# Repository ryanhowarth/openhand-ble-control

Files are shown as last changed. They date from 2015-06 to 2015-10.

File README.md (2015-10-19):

## Openhand Pancake

Wireless control of openhand using either RFduino microcontroller over BLE or Photon microcontroller over WiFi. Solidworks files of the actual pancake are also included. 

### Setup/ Usage
Setup and usage of both microcontrollers is described in README files located in *photon-software* and *rfduino-software*.

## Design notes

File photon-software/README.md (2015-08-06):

## openhand-wifi-control

Wireless control of openhand using an Particle Photon Microcontroller with WiFi to send and receive commands from the Dynamixel.

### Setup
This setup was tested with Xubuntu 14.04 and TL-WR841N Wireless Router.

Connect the Photon to a Wifi Network using the Particle CLI or using the Particle Mobile App.

Connect your computer to the same network and note your computer's local IP Address. Replace the *server_IP* address at the top of the *photon_hand_control.ino* script with the your own local address. Flash this scipt to the photon. 

### Usage
Start the TCP Socket Server by running the following python script. Next, turn on the Photon. The Photon should connect to the TCP Server shortly after booting. If the Photon starts blinking red, it has failed to connect to the server and will try again shortly.

```shell
python openhand_control.py
```

If this script is stopped, the Photon must be power cycled in order to reconnect to a new TCP Server.

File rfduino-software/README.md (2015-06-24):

## openhand-ble-control

Wireless control of openhand using an RFduino with ble to send and receive commands from the Dynamixel.

### Setup

This setup was tested with Xubuntu 14.04 and Bluez 5.21

Upload *rfduino_hand_control.ino* to your RFduino.

Install pygatt to magange the BLE connection: https://github.com/ampledata/pygatt
Using pip:
```shell
pip install pygatt
```
In order to work properly, the pygatt source need to be edited so gatttool works with random device types. 

Bluez version > 5.5 is needed for pygatt. This must be installed from source on Ubuntu. Instructions are below. Download: http://www.bluez.org/download/

 Remove Bluez 4.101 and related packages using synaptic.

 Install Dependencies:
```shell
sudo apt-get install libglib2.0-dev libdbus-1-dev libusb-dev libudev-dev libical-dev libreadline-dev
```

 Run Configuration Script:
 
   *--enable-library* Builds bluez 4 compatible version which some applications could depend on.
   
   *--disable-systemd* Needed if systemd is not installed.
   
```shell
./configure --enable-library --prefix=/usr --mandir=/usr/share/man --sysconfdir=/etc --localstatedir=/var --disable-systemd
```

 Compile and install using checkinstall:
```shell
make
sudo checkinstall
```

 Gatttool does not work correctly right away. Need to copy gatttool to /usr/local/bin/:
```shell
sudo cp attrib/gatttool /usr/local/bin/
```

### Usage
Start device advertising and run ble_interface.py to send and receive hand commands. Enter help to see possible commands. 

```shell
sudo hcitool lescan
python ble_interface.py
```

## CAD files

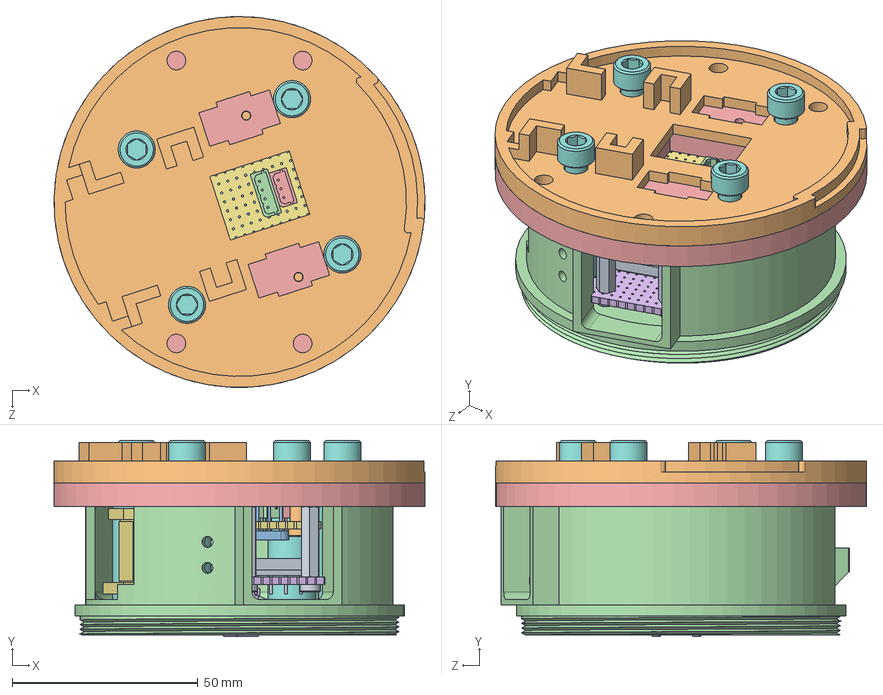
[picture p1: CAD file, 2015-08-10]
cad/Open hand pancake assem.SLDASM
100.0 x 52.8 x 100.0 mm
48V to 12V DC to DC converter
open hand base (a3)
TTL to RS485 converter
WAM_WRIST_ADAPTER_PLATE_updated
pancake structure
perf board top
perf board bottom
M6 25mm Spacer x 4
m3 standoff x 4
m3 4mm spacer x 4
switch
4 pin molex RS486 connector
3 pin molex TTL connector
Highrose connector
micro controller
M6 45mm bolt x 4
m3 6mm length socket cap screw x 4
m3 10mm length socket cap screw x 4
12V to 5V or 3.3V DC to DC converter x 2
pancake cover

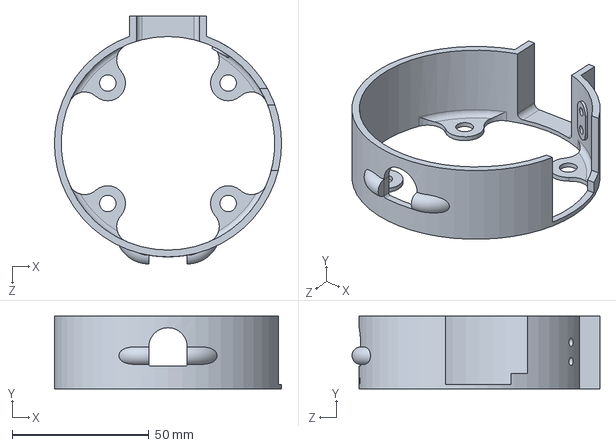
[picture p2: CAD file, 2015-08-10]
cad/pancake cover.SLDPRT
83.0 x 26.5 x 90.6 mm

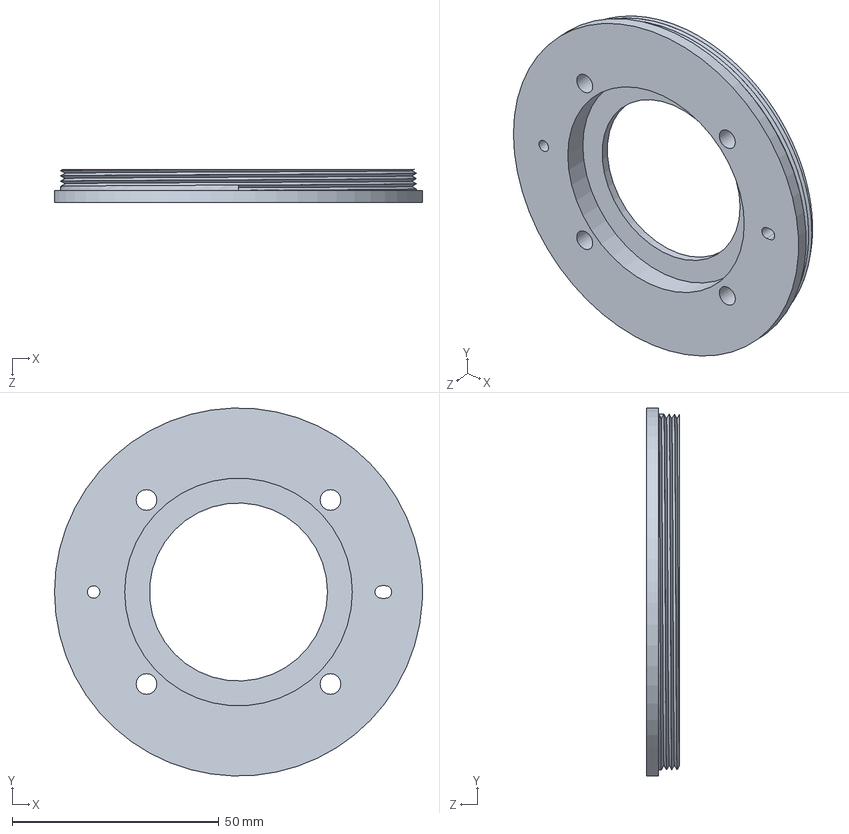
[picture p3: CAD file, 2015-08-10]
cad/WAM_WRIST_ADAPTER_PLATE_updated.SLDPRT
88.9 x 88.9 x 8.08 mm

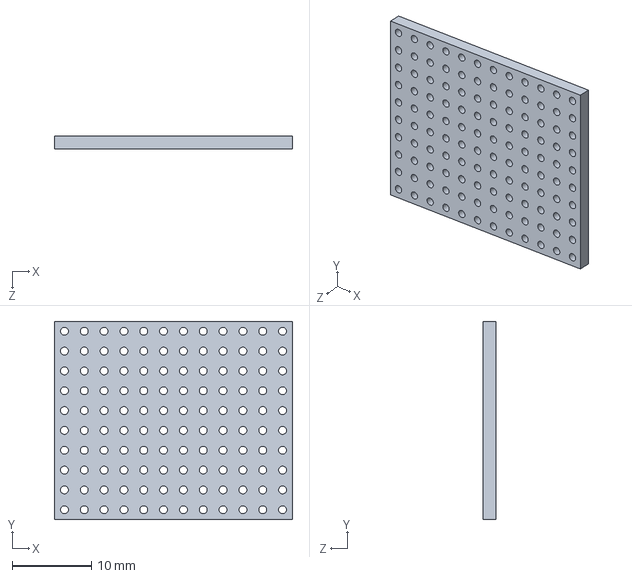
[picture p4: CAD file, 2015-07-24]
cad/sqaure perf board.SLDPRT
30.0 x 25.0 x 1.61 mm

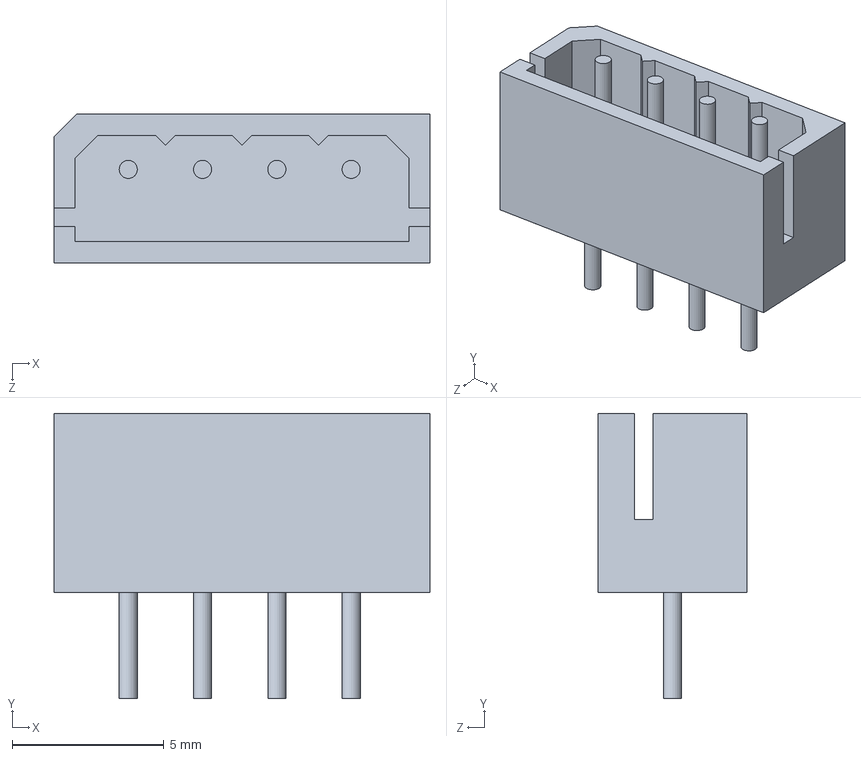
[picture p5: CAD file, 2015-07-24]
cad/4 pin molex RS486 connector.SLDPRT
12.4 x 9.40 x 4.90 mm

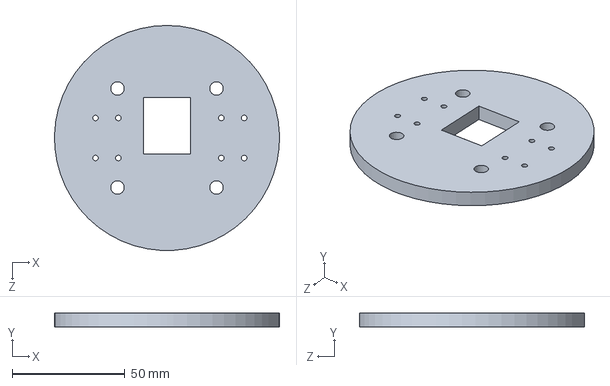
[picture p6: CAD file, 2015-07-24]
cad/pancake structure.SLDPRT
100.0 x 6.35 x 100.0 mm

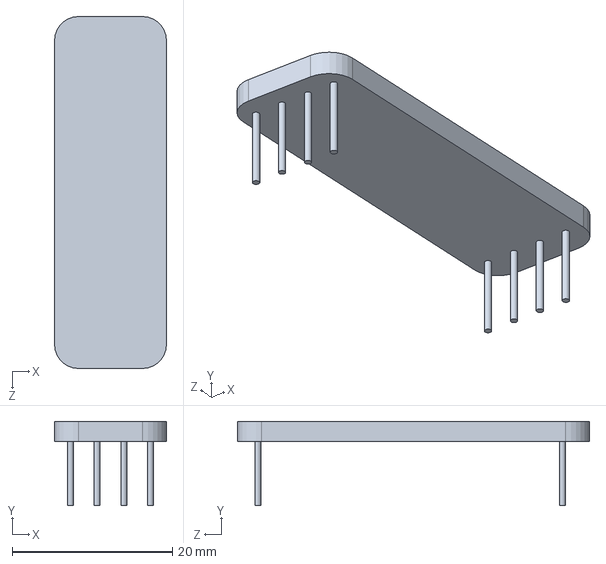
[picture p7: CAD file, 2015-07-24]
cad/TTL to RS485 converter.SLDPRT
14.0 x 10.5 x 44.0 mm

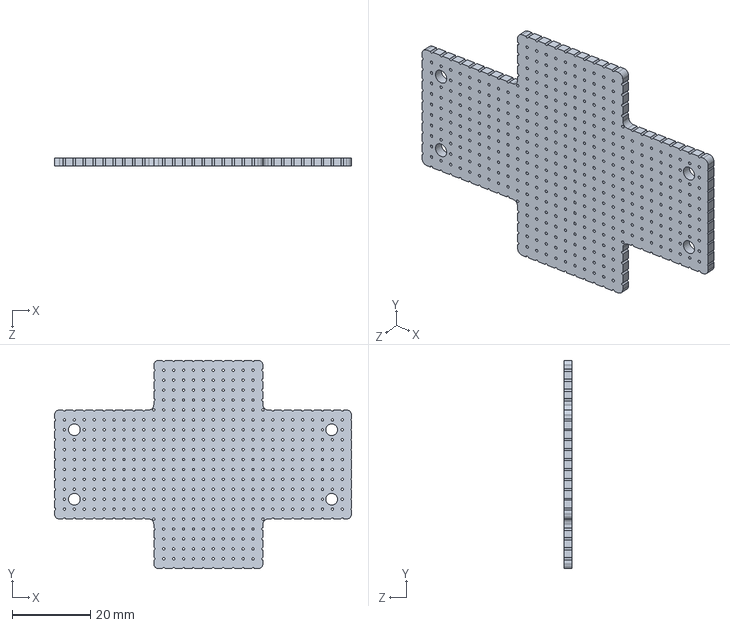
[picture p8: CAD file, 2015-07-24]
cad/perf board top.SLDPRT
76.0 x 53.3 x 2.00 mm

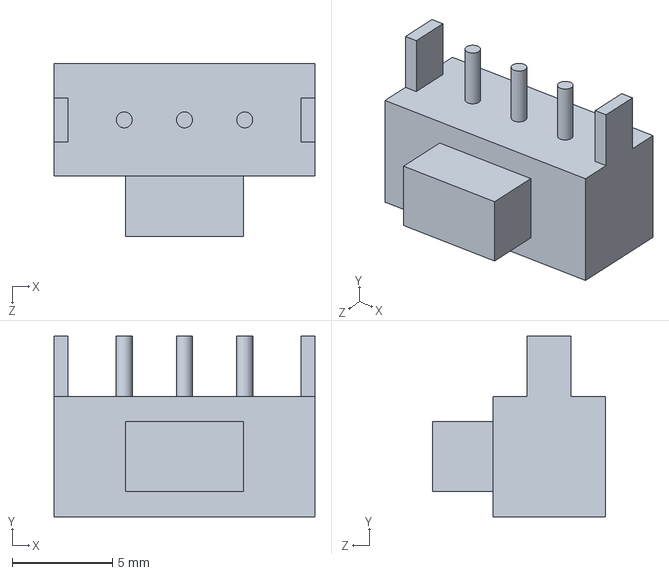
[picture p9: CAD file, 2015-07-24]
cad/switch.SLDPRT
13.0 x 9.00 x 8.60 mm

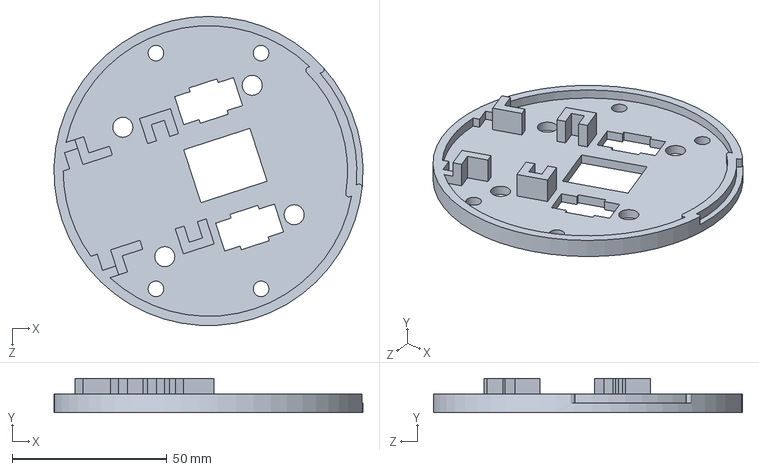
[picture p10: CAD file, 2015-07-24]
cad/open hand base (a3).SLDPRT
100.0 x 11.0 x 100.0 mm

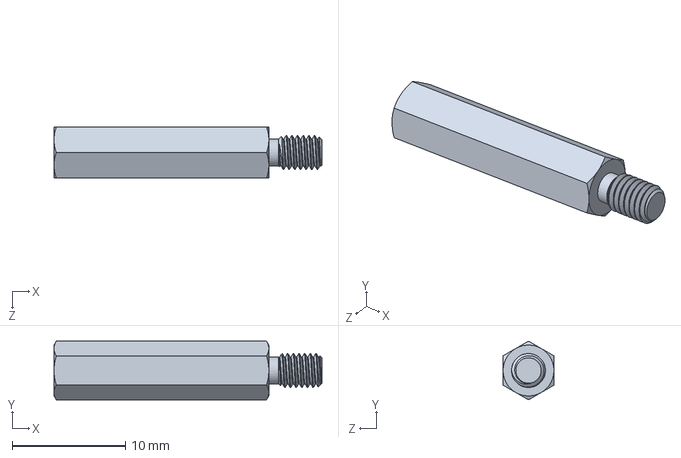
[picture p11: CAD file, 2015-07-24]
cad/m3 standoff.SLDPRT
23.7 x 5.20 x 4.50 mm

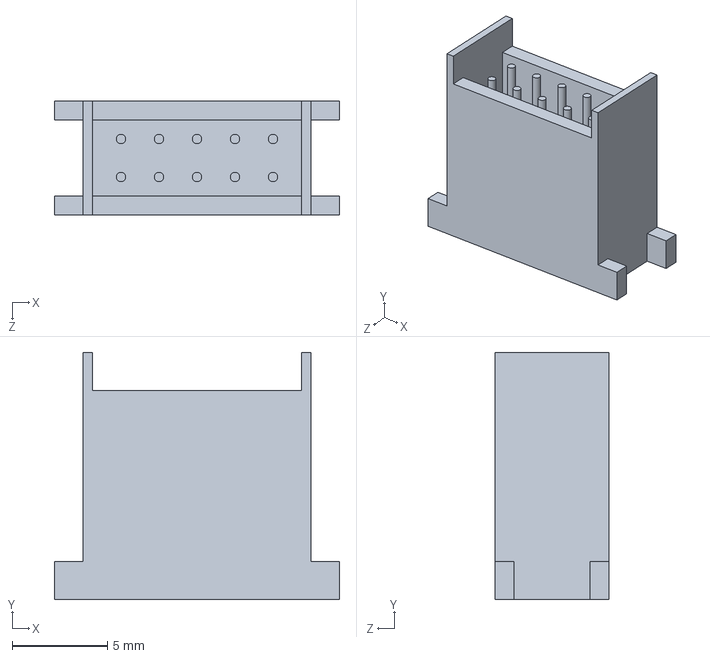
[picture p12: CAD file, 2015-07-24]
cad/Highrose connector.SLDPRT
15.0 x 13.0 x 6.00 mm

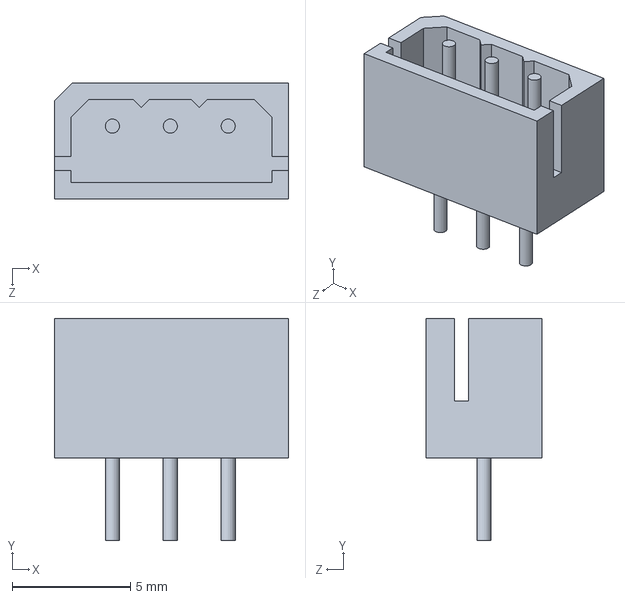
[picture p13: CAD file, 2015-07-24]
cad/3 pin molex TTL connector.SLDPRT
9.90 x 9.40 x 4.90 mm

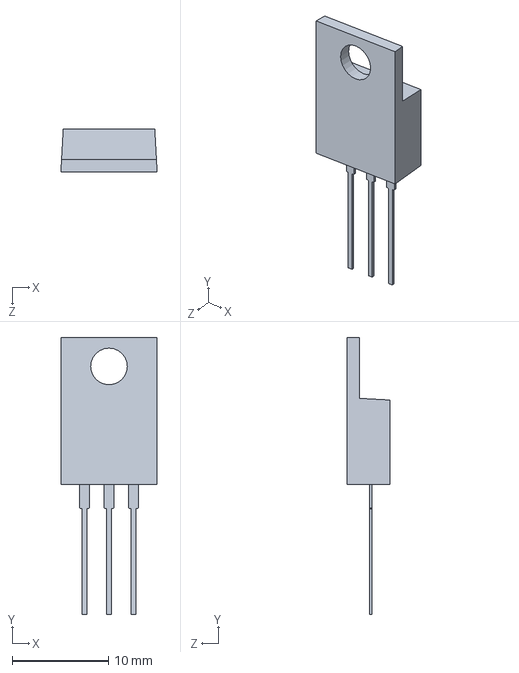
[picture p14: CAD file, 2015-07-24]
cad/12V to 5V or 3.3V DC to DC converter.SLDPRT
10.0 x 28.7 x 4.50 mm

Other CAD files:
cad/micro controller.SLDPRT
cad/48V to 12V DC to DC converter.SLDPRT
cad/angle bracket.SLDPRT
cad/perf board bottom.SLDPRT
cad/M6 25mm Spacer.SLDPRT
cad/M6 45mm bolt.SLDPRT
cad/m3 10mm length socket cap screw.SLDPRT
cad/m3 4mm spacer.SLDPRT
cad/m3 6mm length socket cap screw.SLDPRT
cad/m6 standoffs.SLDPRT
cad/pancake structure drawing.SLDDRW

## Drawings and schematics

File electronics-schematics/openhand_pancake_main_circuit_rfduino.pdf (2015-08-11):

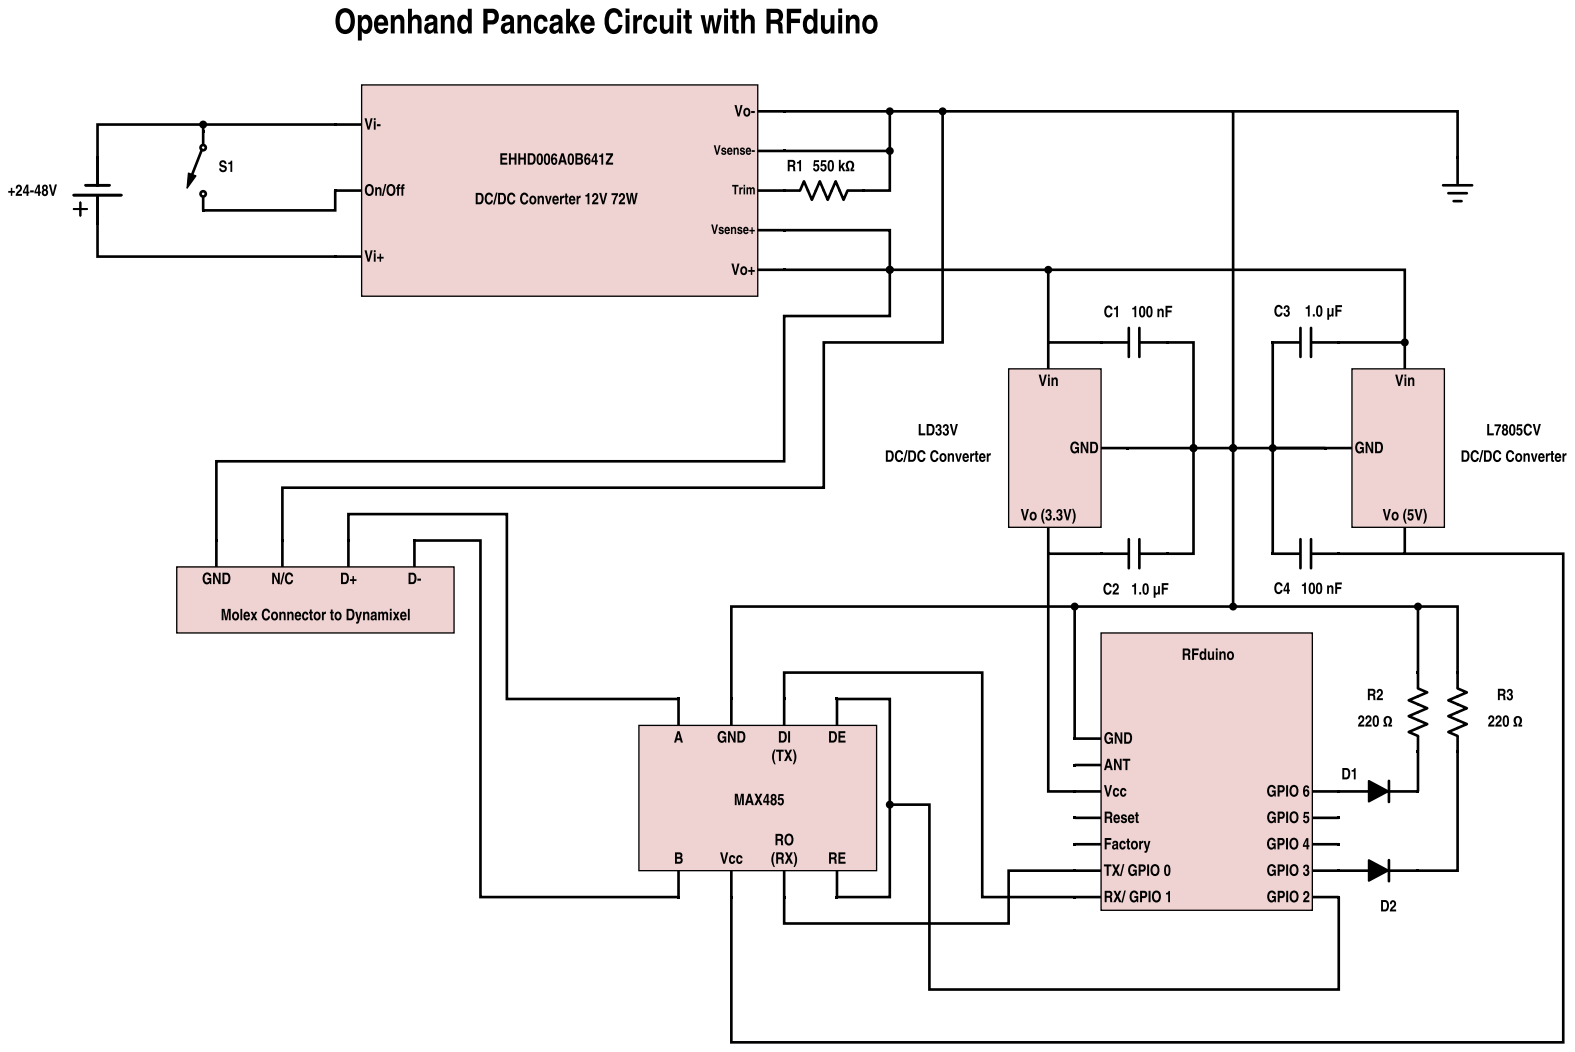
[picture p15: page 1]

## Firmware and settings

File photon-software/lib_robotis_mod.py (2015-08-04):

#!/usr/bin/python
# Copyright (c) 2009, Georgia Tech Research Corporation
# All rights reserved.
# 
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

## Controlling Robotis Dynamixel RX-28 & RX-64 servos from python
## using the Particle Photon Wifi Microcontroller.

## Authors: Travis Deyle, Advait Jain & Marc Killpack (Healthcare Robotics Lab, Georgia Tech.)

##MOD VERSION: 2013, some additional modifications made to make appropriate for both MX/RX series (Raymond R. Ma)

##MOD Version 2015, Added class to interface with Particle Photon Microcontroller (Ryan Howarth).
import serial
import time
import thread
import sys, optparse
import os
import math
import photon_tcp_socket_server as tcp 


#Not used any more. Replaced by photon device class.
class USB2Dynamixel_Device():
    ''' Class that manages serial port contention between servos on same bus
    '''
    def __init__( self, dev_name = '/dev/ttyUSB0', baudrate = 9600 ):
        print("Baudrate: " + str(baudrate)) #Added by Ryan for debugging
        print("Device Name: " + dev_name)   #Added by Ryan for debugging
        
        ''' Commented out code below stores the device name incorrectly on Ubuntu 12.04. 
            Gives runtime error: "Could not find ID on bus" later on in program. -Ryan 5/15/15
        ''' 
        try:
            self.dev_name = string.atoi( dev_name ) # stores the serial port as 0-based integer for Windows
        except:
            self.dev_name = dev_name # stores it as a /dev-mapped string for Linux / Mac
        #if os.name == 'posix':
        #    self.dev_name = dev_name # stores it as a /dev-mapped string for Linux / Mac
        #else:
        #    self.dev_name = string.atoi( dev_name ) # stores the serial port as 0-based integer for Windows

        self.mutex = thread.allocate_lock()	#helps ensure that only a single port is used?
        self.servo_dev = None

        self.acq_mutex()
        self._open_serial( baudrate )
        self.rel_mutex()

    def acq_mutex(self):
        self.mutex.acquire()

    def rel_mutex(self):
        self.mutex.release()

    def send_serial(self, msg):
        # It is up to the caller to acquire / release mutex
        self.servo_dev.flushInput()		#added to remove extra bytes from input buffer
        print ('Send Serial: ' , msg, type(msg)) 
        self.servo_dev.write( msg )

    def read_serial(self, nBytes=1):
        # It is up to the caller to acquire / release mutex
        rep = self.servo_dev.read( nBytes )
        #print ('Read Serial: ' , rep, type(rep)) 
        return rep

    def _open_serial(self, baudrate):
        try:
            self.servo_dev = serial.Serial(self.dev_name, baudrate, timeout=1.0)
            # Closing the device first seems to prevent "Access Denied" errors on WinXP
            # (Conversations with Brian Wu @ MIT on 6/23/2010)
            self.servo_dev.close()  
            self.servo_dev.setParity('N')
            self.servo_dev.setStopbits(1)
            self.servo_dev.open()

            self.servo_dev.flushOutput()
            self.servo_dev.flushInput()

        except (serial.serialutil.SerialException), e:
            raise RuntimeError('lib_robotis: Serial port not found!\n')
        if(self.servo_dev == None):
            raise RuntimeError('lib_robotis: Serial port not found!\n')


#Class to send and read to photon device. Tcp connection should not be shared 
class Photon_Device():

    tcp_client = []
    packet_recv = []
    index = 0

    def __init__(self, port=1234, local_ip='192.168.0.105'):
        #Start wifi connection.
        self.tcp_client = tcp.photon_tcp_socket_server()
    
    def send_serial(self, msg):
        print ('Send Serial: ' , msg, type(msg))
        self.index = 0 
        self.packet_recv = self.tcp_client.send( msg )
        print 'Packet Recv: ', self.packet_recv

    def read_serial(self, nBytes=1):
        temp = []
        print 'nBytes: ', nBytes
        print 'index: ', self.index
        for i in range(nBytes):
            temp.append(self.packet_recv[self.index + i])
        self.index += nBytes

        print 'temp in read serail: ', temp
        return temp

class Robotis_Servo():
    ''' Class to use a robotis RX-28 or RX-64 servo.
    '''
    def __init__(self, Photon_Device, servo_id, series = None ):
        ''' Photon_Device- Photon Wifi Microcontroller that sends and receives
                            packets over a tcp sockets and passes them along to the Dynamixel.
            servo_id - servo ids connected to USB2Dynamixel 1,2,3,4 ... (1 to 253)
                       [0 is broadcast if memory serves]
            series - Just a convenience for defining "good" defaults on MX series.
                     When set to "MX" it uses these values, otherwise it uses values
                     better for AX / RX series.  Any of the defaults can be overloaded
                     on a servo-by-servo bases in servo_config.py
        '''
        
	self.series = series;	#record dynamixel series
        self.return_delay = 250 * 2e-6	#default return delay
        # To change the defaults, load some or all changes into servo_config.py
        if series == 'MX':			#MX series generally has 4x the travel and maximums of RX
            defaults = {
                'home_encoder': 0x7FF,
                'max_encoder': 0xFFF,
                'rad_per_enc': math.radians(360.0) / 0xFFF, 
                'max_ang': math.radians(180),
                'min_ang': math.radians(-180),
                'flipped': False,
                'max_speed': math.radians(100)
                }
        else: # Common settings for RX-series.  Can overload in servo_config.py
            defaults = {
                'home_encoder': 0x200,
                'max_encoder': 0x3FF,  # Assumes 0 is min.
                'rad_per_enc': math.radians(300.0) / 1024.0, 
                'max_ang': math.radians(148),
                'min_ang': math.radians(-148),
                'flipped': False,
                'max_speed': math.radians(100)
                }
                

        # Error Checking
        #if USB2Dynamixel == None:
        #    raise RuntimeError('lib_robotis: Robotis Servo requires USB2Dynamixel!\n')
        #else:
        self.dyn = Photon_Device
        #    self.dyn.servo_dev.flush()

        # ID exists on bus?
        self.servo_id = servo_id
        #try:
        #    self.read_address(3)
        #except Exception as inst:
        #    raise RuntimeError('lib_robotis: Error encountered.  Could not find ID (%d) on bus (%s), or USB2Dynamixel 3-way switch in wrong position.\n' %
        #                       ( servo_id, self.dyn.dev_name ))

        # Set Return Delay time - Used to determine when next status can be requested
        data = self.read_address( 0x05, 1)
        self.return_delay = data[0] * 3e-6

        self.settings = {}
        #removed external servo settings file to simplify things (we usually only deal with MX or RX, and both settings are included above)

        # Set to default any parameter not specified in servo_config
        for key in defaults.keys():
            if self.settings.has_key( key ):
                pass
            else:
                self.settings[ key ] = defaults[ key ]	#defaults dict moved into settings component

    def init_cont_turn(self):
        '''sets CCW angle limit to zero and allows continuous turning (good for wheels).
        After calling this method, simply use 'set_angvel' to command rotation.  This 
        rotation is proportional to torque according to Robotis documentation.
        '''
        self.write_address(0x08, [0,0])

    #UPDATED: set limits based on servo max encoder, reset speed to 0
        #should work properly for both RX/MX series
    def kill_cont_turn(self):
        '''resets CCW angle limits to allow commands through 'move_angle' again
        '''

	max_encoder = self.settings['max_encoder']
	hi,lo = max_encoder / 256, max_encoder % 256	#addition made to reset encoder appropriately for both series
        self.write_address(0x08, [lo,hi])

    def is_moving(self):
        ''' returns True if servo is moving.
        '''
        data = self.read_address( 0x2e, 1 )
        return data[0] != 0

    def read_voltage(self):
        ''' returns voltage (Volts)
        '''
        data = self.read_address( 0x2a, 1 )
        return data[0] / 10.

    def read_temperature(self):
        ''' returns the temperature (Celcius)
        '''
        data = self.read_address( 0x2b, 1 )
        return data[0]

    def read_load(self):
        ''' number proportional to the torque applied by the servo.
            sign etc. might vary with how the servo is mounted.
        '''
        data = self.read_address( 0x28, 2 )
        load = data[0] + data[1] * 256
        if load>1024:
            return 1024-load
        else:
            return load

    #ADDED: current functionality only available for MX-64 series:
    def read_current(self):
        if self.series=='MX':
            data = self.read_address( 0x44, 2 )	#current spans addresses 0x44 and 0x45
            curr = data[0] + data[1] * 256
            return 4.5*(curr-2048)		#in mA
        else:
            return 0.

    #ADDED: speed address same for both MX/RX series
    def read_speed(self):
        data = self.read_address( 0x26, 2 )
        speed = data[0] + data[1] * 256
        if speed>1024:
            return float(1024-speed)/1024.0
        else:
            return float(speed)/1024.0

    #both moving speed in joint mode (between designated positions) as well as wheel mode (which only sets direction in operation)
    def apply_speed(self,amnt):
        amnt = max(0.,min(abs(amnt),1.0))
        speed_val = int(amnt*1023)
        if speed_val < 0:
            speed_val = speed_val+1024
        hi,lo = speed_val / 256, speed_val % 256
        self.write_address(0x20,[lo,hi])

    def read_encoder(self):
        ''' returns position in encoder ticks
        '''
        data = self.read_address( 0x24, 2 )
        enc_val = data[0] + data[1] * 256
        return enc_val

    def read_target_encoder(self):
        data = self.read_address( 0x1e, 2 )
        enc_val = data[0] + data[1] * 256
        return enc_val

    def read_angle(self):	#based entirely off of the encoder setting
        ''' returns the current servo angle (radians)
        '''
        ang = (self.read_encoder() - self.settings['home_encoder']) * self.settings['rad_per_enc']
        if self.settings['flipped']:
            ang = ang * -1.0
        return ang

    #ADDED: reading/setting the max torque output (at different addresses)
    def read_max_torque(self):	#set twice, but we'll read the first instance
        data = self.read_address( 0x0e, 2 )
        torque = data[0] + data[1] * 256
        return torque

    def apply_max_torque(self,val):	#unlike speed, 0 is not max torque; no mode dependencies to use/set
	amnt = max(0.,min(abs(val),1.0))
	n = int(amnt*1023)
        n = min(max(n,0), 1023)		#no scaling issues between MX and RX like with position
        hi,lo = n / 256, n % 256
        print("hi, lo: ",lo,hi)
        self.write_address( 0x22, [lo,hi])
        return self.write_address( 0x0e, [lo,hi])

    #alternative approach to move_to_encoder, except w/ arbitrary angle setting
    def move_angle(self, ang, angvel=None, blocking=True):
        ''' move to angle (radians)
        '''
        if angvel == None:
            angvel = self.settings['max_speed']

        if angvel > self.settings['max_speed']:
            print 'lib_robotis.move_angle: angvel too high - %.2f deg/s' % (math.degrees(angvel))
            print 'lib_robotis.ignoring move command.'
            return

        if ang > self.settings['max_ang'] or ang < self.settings['min_ang']:
            print 'lib_robotis.move_angle: angle out of range- ', math.degrees(ang)
            print 'lib_robotis.ignoring move command.'
            return
        
        self.set_angvel(angvel)

        if self.settings['flipped']:
            ang = ang * -1.0
        enc_tics = int(round( ang / self.settings['rad_per_enc'] ))
        enc_tics += self.settings['home_encoder']
        self.move_to_encoder( enc_tics )

        if blocking == True:
            while(self.is_moving()):
                continue

    def move_to_encoder(self, n):
        ''' move to encoder position n
        '''
        # In some border cases, we can end up above/below the encoder limits.
        #   eg. int(round(math.radians( 180 ) / ( math.radians(360) / 0xFFF ))) + 0x7FF => -1
        n = min( max( n, 0 ), self.settings['max_encoder'] ) 
        hi,lo = n / 256, n % 256
        return self.write_address( 0x1e, [lo,hi] )

    #ADDED: reading the goal encoder position that the user has specified    
        #useful for slow motions or torque-limited motions to find distance to goal
    def read_goal(self):
        data = self.read_address( 0x1e, 2)
        enc_val = data[0] + data[1] * 256
        return enc_val

    #ADDED: enabling torque control mode for the MX-64 series and above ONLY:
    def enable_torque_mode(self):
        if self.series=='MX':
            return self.write_address(0x46, [1])
        else:
            return 0
    def disable_torque_mode(self):
        if self.series=='MX':
            return self.write_address(0x46, [0])
        else:
            return 0
    def apply_torque(self,amnt):
        if self.series=='MX':
            amnt = max(0.,min(abs(amnt),1.0))
            torque_val = int(amnt*1023)
            if torque_val < 0:
                torque_val = torque_val+1024
            hi,lo = torque_val / 256, torque_val % 256
            return self.write_address(0x47,[lo,hi])
        else:
            return 0

    #disabling/enabling address 18 effectively shuts down motor output
        #different from torque mode that's available in the MX models
        #USE ONLY AS ON/OFF quick shutdown control
    def enable_torque(self):
        return self.write_address(0x18, [1])

    def disable_torque(self):
        return self.write_address(0x18, [0])

    #same as apply_speed, except set rad/sec as opposed to single value scalar
    def set_angvel(self, angvel):
        ''' angvel - in rad/sec
        '''     
        rpm = angvel / (2 * math.pi) * 60.0
        angvel_enc = int(round( rpm / 0.111 ))
        if angvel_enc<0:
            hi,lo = abs(angvel_enc) / 256 + 4, abs(angvel_enc) % 256
        else:
            hi,lo = angvel_enc / 256, angvel_enc % 256
        
        return self.write_address( 0x20, [lo,hi] )

    def write_id(self, id):
        ''' changes the servo id
        '''
        return self.write_address( 0x03, [id] )

    def __calc_checksum(self, msg):
        chksum = 0
        for m in msg:
            chksum += m
        chksum = ( ~chksum ) % 256
        return chksum

    def ping(self):
        return self.read_address(self,0x01,nBytes=1)

    def read_address(self, address, nBytes=1):
        ''' reads nBytes from address on the servo.
            returns [n1,n2 ...] (list of parameters)
        '''
        msg = [ 0x02, address, nBytes ]
        return self.send_instruction( msg, self.servo_id )

    def write_address(self, address, data):
        ''' writes data at the address.
            data = [n1,n2 ...] list of numbers.
            return [n1,n2 ...] (list of return parameters)
        '''
        msg = [ 0x03, address ] + data
        return self.send_instruction( msg, self.servo_id )

    def send_instruction(self, instruction, id):
        time.sleep(self.return_delay)	#helps w/ communication consistency?

        msg = [ id, len(instruction) + 1 ] + instruction # instruction includes the command (1 byte + parameters. length = parameters+2)

        chksum = self.__calc_checksum( msg )
        msg = [ 0xff, 0xff ] + msg + [chksum]
        
        print (type(msg))
        print 'send_instruction: ' , msg
        #elf.dyn.acq_mutex()
        
        self.send_serial( msg )
        data, err = self.receive_reply()
        #except Exception as inst:
        #    self.dyn.rel_mutex()
        #    raise RuntimeError(repr(str(inst)))
        #self.dyn.rel_mutex()
        
        if err != 0:
            self.process_err( err )
        
        return data

    def process_err( self, err ):
        raise RuntimeError('lib_robotis: An error occurred: %d\n' % err)

    def receive_reply(self):
        start = self.dyn.read_serial( 2 )	#from pydynamixel: possible that these contain empty bytes
        servo_id = self.dyn.read_serial( 1 )

        while servo_id=='\xff':
            servo_id = self.dyn.read_serial( 1 )	#on Sparkfun USB-to-RS485 chip, more than 3 header bytes are sometimes set - apparently not an issue with the USB2Dynamixel

        #if type(servo_id) is not str or len(servo_id)!=1:
        #    raise RuntimeError('lib_robotis: Invalid message headers, got servo id of type: '+repr(type(servo_id))+' and length: '+repr(len(servo_id)))
        #if ord(servo_id) != self.servo_id:
        #    raise RuntimeError('lib_robotis: Incorrect servo ID received')
        data_len = self.dyn.read_serial( 1 )
        print 'data_len: ', data_len
        print 'str(data_len): ', str(data_len), (data_len[0])
        err = self.dyn.read_serial( 1 )
        print 'err: ', err
        print ord(str(data_len[0]))
        data = self.dyn.read_serial( int(str(data_len[0])) - 2 )
        print 'data: ', data
        checksum = self.dyn.read_serial( 1 ) 		#checksum is read but never compared...(by design, according to original lib_robotis.py)
        #print( "Receive reply: ", [ord(str(v)) for v in data], ord(str(err)))
        return [int(str(v)) for v in data], int(str(err[0]))
        

    def send_serial(self, msg):
        """ sends the command to the servo
        """
        out = ''
        for m in msg:
            out += chr(m)
        self.dyn.send_serial( out )

#def find_servos(dyn):
#    ''' Finds all servo IDs on the USB2Dynamixel '''
#    servos = []
#    dyn.servo_dev.setTimeout( 0.03 ) # To make the scan faster
#    for i in xrange(254):
#        try:
#            s = Robotis_Servo( dyn, i )
#            print '\n FOUND A SERVO @ ID %d\n' % i
#            servos.append( i )
#        except:
#            pass
#    dyn.servo_dev.setTimeout( 1.0 ) # Restore to original
#    return servos


def recover_servo(dyn):
    ''' Recovers a bricked servo by booting into diagnostic bootloader and resetting '''
    raw_input('Make sure only one servo connected to USB2Dynamixel Device [ENTER]')
    raw_input('Disconnect power from the servo, but leave USB2Dynamixel connected to USB. [ENTER]')

    dyn.servo_dev.setBaudrate( 57600 )
    
    print 'Get Ready.  Be ready to reconnect servo power when I say \'GO!\''
    print 'After a second, the red LED should become permanently lit.'
    print 'After that happens, Ctrl + C to kill this program.'
    print
    print 'Then, you will need to use a serial terminal to issue additional commands.',
    print 'Here is an example using screen as serial terminal:'
    print
    print 'Command Line:  screen /dev/robot/servo_left 57600'
    print 'Type: \'h\''
    print 'Response: Command : L(oad),G(o),S(ystem),A(pplication),R(eset),D(ump),C(lear)'
    print 'Type: \'C\''
    print 'Response:  * Clear EEPROM '
    print 'Type: \'A\''
    print 'Response: * Application Mode'
    print 'Type: \'G\''
    print 'Response:  * Go'
    print
    print 'Should now be able to reconnect to the servo using ID 1'
    print
    print
    raw_input('Ready to reconnect power? [ENTER]')
    print 'GO!'

    while True:
        s.write('#')
        time.sleep(0.0001)


if __name__ == '__main__':

    p = optparse.OptionParser()
    p.add_option('-d', action='store', type='string', dest='dev_name',
                 help='Required: Device string for USB2Dynamixel. [i.e. /dev/ttyUSB0 for Linux, \'0\' (for COM1) on Windows]')
    p.add_option('--scan', action='store_true', dest='scan', default=False,
                 help='Scan the device for servo IDs attached.')
    p.add_option('--recover', action='store_true', dest='recover', default=False,
                 help='Recover from a bricked servo (restores to factory defaults).')
    p.add_option('--ang', action='store', type='float', dest='ang',
                 help='Angle to move the servo to (degrees).')
    p.add_option('--ang_vel', action='store', type='float', dest='ang_vel',
                 help='angular velocity. (degrees/sec) [default = 50]', default=50)
    p.add_option('--id', action='store', type='int', dest='id',
                 help='id of servo to connect to, [default = 1]', default=1)
    p.add_option('--baud', action='store', type='int', dest='baud',
                 help='baudrate for USB2Dynamixel connection [default = 57600]', default=57600)

    opt, args = p.parse_args()

    if opt.dev_name == None:
        p.print_help()
        sys.exit(0)

    dyn = USB2Dynamixel_Device(opt.dev_name, opt.baud)

    if opt.scan:
        find_servos( dyn )

    if opt.recover:
        recover_servo( dyn )

    if opt.ang != None:
        servo = Robotis_Servo( dyn, opt.id )
        servo.move_angle( math.radians(opt.ang), math.radians(opt.ang_vel) )

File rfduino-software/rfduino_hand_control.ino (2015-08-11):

/*
RFdunio sketch that sends and recevies commands to a dynamixel.

*/

#include <RFduinoBLE.h>

// (shows when the RFduino is advertising or not)
int advertisement_led = 3;

// Shows when connected to device
int connection_led = 2;

// The pin to be used for enable/disable signal
int txrx_pin = 6;

// Debug pins
int debug = 4;
int debugtwo = 3;

//Detmines whether the hand is currently closing.
boolean closing =  false;

void setup() {

  //Change the advertisement Interval to be small
  int interval = 20;
  RFduinoBLE.advertisementInterval = interval;

  // led used to indicate that the RFduino is advertising
  pinMode(advertisement_led, OUTPUT);

  // led used to indicate that the RFduino is connected
  pinMode(connection_led, OUTPUT);

  delay(500); //Let dynamixel start up

  // Pin to control direction of information (TX/RX)
  pinMode(txrx_pin, OUTPUT);
  digitalWrite(txrx_pin, LOW);

  //Debugging Pins
  pinMode(debug, OUTPUT);
  pinMode(debugtwo, OUTPUT);

  //Start Serial Connection
  Serial.begin(9600);

  // start the BLE stack
  RFduinoBLE.begin();


}

void loop() {
  //No delay (Constantly Looping)
  RFduino_ULPDelay(0);

  //Better to start the control loop here than in the interupt function.
  if (closing)
  {
    control_loop();
  }

  //Reads commands from Dynamixel and sends them over BLE to Laptop
  if (Serial.available() > 0 && !closing ) {
    digitalWrite(txrx_pin, LOW); //Switch to receive data from dynamixel
    char dataRead[8] = {};
    Serial.readBytes(dataRead, 8);
    RFduinoBLE.send(dataRead, 8);
  }

  // switch to lower power mode
  //RFduino_ULPDelay(INFINITE);
  // sample once per second
  //RFduino_ULPDelay( SECONDS(1) );
}

//Monitors position and/or load on the hand while the hand is closing or opening. (Not currently used.)
void control_loop()
{
  while (closing)
  {
    check_speed();
    delay(25); //Weird behavior without this delay
    if (Serial.available() > 0) {
      digitalWrite(txrx_pin, LOW);
      char dataRead[8] = {};
      Serial.readBytes(dataRead, 8);

      int speed_val = get_value(dataRead);
      if (speed_val < 5)
      {
        get_encoder_value();
        closing = false;
      }
      else if (speed_val > 5) {
        digitalWrite(debug, !digitalRead(debug));
      }
      delay(25);
    }
  }

}

//Take packets and return the relevent information. (Even if some of beginning bytes are missing).
int get_value(char *dataRead)
{
  int servo_id = 1;
  for (int i = 0; i < sizeof(dataRead) / sizeof(char); i++) {
    int value  = int(dataRead[i]);
    if (value == servo_id) {
      int data = int(dataRead[i + 3]);
      if (data > 20) {
        //digitalWrite(debug, HIGH);
      }
      return data;
    }
  }
  return -1;
}

void RFduinoBLE_onAdvertisement(bool start)
{
  // turn the red led on if we start advertisement, and turn it
  // off if we stop advertisement
  if (start)
    digitalWrite(advertisement_led, HIGH);
  else
    digitalWrite(advertisement_led, LOW);
}

void RFduinoBLE_onConnect()
{
  digitalWrite(connection_led, HIGH);
}

void RFduinoBLE_onDisconnect()
{
  digitalWrite(connection_led, LOW);
}

/*
  Recevies Commands from Computer and Sends them to Dynamixel
  This is an interrupt function. Strange things occur if program spends too much time in here.
*/
void RFduinoBLE_onReceive(char *data, int len)
{

  uint8_t a = data[0];
  byte hex_byte[len];
  for (int i = 0; i < len; i++) {
    hex_byte[i] = '\x00' + int(data[i]);
  }

  //Not used. (For monitoring speed/ load while closing)
  if (int(data[5]) == -1) {
    //enable_torque_mode();
    send_to_servo(hex_byte, len);
    delay(25);
    set_moving_speed();
    closing = true;
  }
  else
  {
    send_to_servo(hex_byte, len);
  }
}

/Sends hexadecimal packets to the servo.
void send_to_servo(byte *data, int len)
{
  digitalWrite(txrx_pin, HIGH); //Switch to TX mode before sending data
  delay(10);                    //Allow this to take effect
  for (int i = 0; i < len; i++) {
    delay(1); // Need spacing between bytes for some reason?
    Serial.write(data[i]);
  }
  delayMicroseconds(1200); //Allow last bit to go through before switching to RX (at 9600 baud)
  digitalWrite(txrx_pin, LOW);
}




void check_load()
{
  byte load_packet[] = {'\xff', '\xff', '\x01', '\x04', '\x02', '\x28', '\x02', '0xCE'};
  send_to_servo(load_packet, sizeof(load_packet) / sizeof(byte) );
}

void check_speed()
{
  byte speed_packet[] = {'\xff', '\xff', '\x01', '\x04', '\x02', '\x26', '\x02', '\xD0'};
  send_to_servo(speed_packet, sizeof(speed_packet) / sizeof(byte) );
}


void enable_torque_mode()
{
  byte torque_packet[] = {'\xff', '\xff', '\x01', '\x04', '\x03', '\x46', '\x01', '\xAD'};
  send_to_servo(torque_packet, sizeof(torque_packet) / sizeof(byte) );
}

void disable_torque_mode()
{
  byte torque_packet[] = {'\xff', '\xff', '\x01', '\x04', '\x03', '\x46', '\x00', '\xAE'};
  send_to_servo(torque_packet, sizeof(torque_packet) / sizeof(byte) );
}

//Not Tested
int calc_checksum(byte msg[])
{
  byte checksum = 0;
  int len = sizeof(msg) / sizeof(byte);
  for(int i = 0; i < len; i++) {
    checksum += msg[i];
  }
  checksum = (~checksum) % 256;
  
}

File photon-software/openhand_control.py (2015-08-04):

#!/usr/bin/python

import binascii
import struct
import time
import photon_tcp_socket_server as tcp 



#This class interfaces with a RFduino over BLE to Control an Openhand
#using a Dynamixel servo.
class openhand_control():

    servo_id = [1] #default
    max_torque = 0.3
    tcp_client = [] 
     
    #Commands supported by this class.
    led_on = [3, 25, 1] 
    led_off = [3, 25, 0] 
    temperature = [2, 43, 1] 
    load = [2, 40, 2]
    position = [2, 36, 2]
    speed = [2, 38, 2]
    #close_hand = [3, 71, 100, 5]
    close_hand = [3, 30, 0, 7]
    open_hand = [3, 30, 0, 1]
    set_torque = [3, 34, 0, 0]
    set_torque_eeprom = [3, 14, 0, 0]
    
    def __init__(self, port=1234, local_ip='192.168.0.105'):
        #Start wifi connection.
        self.tcp_client = tcp.photon_tcp_socket_server()

    #Reads data out of incoming packets.
    #@profile
    def _get_value(self, data):
        for i in range(8):
            if (int(data[i]) == 1):
                return data[ (i+3) ]
        return -1

    #Caulatates Checksum before sendings commands to dynamixel.
    def _calc_checksum(self, msg):
        checksum = 0
        for m in msg:
            checksum += m
        checksum = ( ~checksum ) % 256
        return [checksum]

    #Recevices Max Torque Value from command line.
    #Converts value to dynamixel syntax and sends the packet to rfduino.
    def set_max_torque(self, val):
        if not val.isdigit():
            print 'Invalid input'
            return
        
        torque_val = min(int(float(val)/100 * 1024), 1024) #percentage to dynamixel scale (0 - 1024)
        hi,lo = torque_val / 256, torque_val % 256
        self.set_torque[2:4] = [lo, hi]
        self.set_torque_eeprom[2:4] = [lo, hi]
        self.send_packet(self.set_torque)
        self.send_packet(self.set_torque_eeprom)
    
    #Takes command and appends the start address, servo ID, and checksum.
    #Then sends it to the rf duino
    def send_packet(self, command):
        start_address = [255, 255]
        cmd_length = [len(command) + 1]
        packet = start_address + self.servo_id + cmd_length + command
        packet = packet + self._calc_checksum(packet[2:])
        print (packet)
        print (str(packet))
        return self.tcp_client.send(packet)

    #Prints all possible commands to command line.
    def print_commands(self):
        print(' ')
        print('     c,       Close the Hand')
        print('     o,       Open the Hand')
        print('     s,       Set Maximum Torue of Dynamixel')
        print('     1,       Turn Dynamixel LED On')
        print('     0,       Turn Dynamixel LED Off')
        print('     t,       Read the Temperature of Dynamixel')
        print('     l,       Read the Load of Dynamixel')
        print('     t,       Read the Position of Dynamixel')
        print('     v,       Read the Speed of Dynamixel')
        print('     close,   Close connection between clients. (TCP Server continues to run and listen for clients.)')
        print('     quit,    Disconnect Bluetooth connection and end script')
        print('     help,    Print all commands')
        print(' ')

#Main control loop that recevies commands from command line and interprets them.
    def main(self):
        try:
            input_str = ''
            while input_str != 'quit':
                input_str = raw_input("Hand Control Enter Command: ") 
                if (input_str == '1'):
                    print("-----Turning the LED On-----")
                    self.send_packet(self.led_on)
                elif (input_str == '0'):
                    print("-----Turning the LED Off-----")
                    self.send_packet(self.led_off)
                elif (input_str == 'l'):
                    print("-----Reading the Load-----")
                    return_packet = self.send_packet(self.load)
                    print 'Load: ' + str(self._get_value(return_packet))
                elif (input_str == 'p'):
                    print("-----Reading the Position-----")
                    return_packet = self.send_packet(self.position)
                    print 'Pos: ' + str(self._get_value(return_packet))
                elif (input_str == 't'):
                    print("------Reading the Temp--------")
                    return_packet = self.send_packet(self.temperature)
                    print 'Temp: ' + str(self._get_value(return_packet))
                elif (input_str == 'v'):
                    print("------Reading the Speed--------")
                    return_packet = self.send_packet(self.speed)
                    print 'Speed: ' + str(self._get_value(return_packet))
            
                elif (input_str == 'o'):
                    print("------Opening the Hand--------")
                    self.send_packet(self.open_hand)
                elif (input_str == 'c'):
                    print("------Closing the Hand--------")
                    self.send_packet(self.close_hand)
                elif (input_str == 's'):
                    val = raw_input("Enter Torque Percentage(0-100) Values > 40 can break cables: ")
                    self.set_max_torque(val)
                elif (input_str == 'close'):
                    self.tcp_client.close_connection()
                elif (input_str == 'help'):
                    self.print_commands()
        finally:
            self.tcp_client.close_server()


x = openhand_control()
x.main()

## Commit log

2015-06-23 Added up to date CAD files
    [12V to 5V or 3.3V DC to DC converter.SLDPRT, 3 pin molex TTL connector.SLDPRT, 4 pin molex RS486 connector.SLDPRT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]
2015-06-24 Max torque is set in the eeprom as well as the ram of the servo when changed from command line.
2015-06-29 Small changes to cad files.
    [48V to 12V DC to DC converter.SLDPRT, Open hand pancake assem.SLDASM, TTL to RS485 converter.SLDPRT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]
2015-07-14 Minor Cad Updates
    [Open hand pancake assem.SLDASM, perf board top.SLDPRT]
2015-07-14 Small cosmetic changes prior to attempting to add control based servo load.
2015-07-14 Updated the timing of sending data to the Dynamixel. It doesn't delay for as long after sending the last byte in a packet. This helps with losing less bytes when reading data back from the Dynamixel.
    [rfduino_hand_control.ino]
2015-07-24 Updated pin assignment to reflect wireing on perf board. Added some functionality for torque mode.
2015-07-24 Updated cad models to reflect the pancake as it was built.
    [12V to 5V or 3.3V DC to DC converter.SLDPRT, 3 pin molex TTL connector.SLDPRT, 4 pin molex RS486 connector.SLDPRT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]
2015-07-31 Updated TCP socket server to use pyhton select library for resource control. Lowered latency of sending servo commands and simplified the photon script.
2015-08-10 Added pancake cover model.
    [Open hand pancake assem.SLDASM, WAM_WRIST_ADAPTER_PLATE_updated.SLDPRT, pancake cover.SLDPRT]
2015-08-11 Added initialization function. Automatically finds the correct open and close values on servo instead of being set manually by trial and error.
    [ble_interface.py, rfduino_hand_control.ino]
